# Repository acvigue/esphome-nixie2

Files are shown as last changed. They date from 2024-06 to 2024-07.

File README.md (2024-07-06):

# ESPHome for Nixie2

Includes custom component for HV5222 low-side shift register

Read more [here](https://vigue.me/nixie-clock)

Altium 3D Viewer & Assembly Preview: [here](https://365.altium.com/files/F7F2C198-6388-416A-9E94-9685C6B443AA)

Example configuration:

```yaml
esphome:
  name: nixieclock
  friendly_name: nixieclock
  on_boot:
    then:
      - number.set:
          id: nixie_1
          value: 9
      - number.set:
          id: nixie_2
          value: 9
      - number.set:
          id: nixie_3
          value: 9
      - number.set:
          id: nixie_4
          value: 9
      - number.set:
          id: nixie_5
          value: 9
      - number.set:
          id: nixie_6
          value: 9

esp32:
  board: esp32-s3-devkitc-1
  framework:
    type: esp-idf

# Enable logging
logger:
  level: WARN

external_components:
  - source: github://acvigue/esphome-nixie2
    components: [hv5222]
    refresh: 1s

# Enable Home Assistant API
api:
  encryption:
    key: "##########"

ota:
  - platform: esphome
    password: "##########"

wifi:
  ssid: !secret wifi_ssid
  password: !secret wifi_password

  # Enable fallback hotspot (captive portal) in case wifi connection fails
  ap:
    ssid: "Nixieclock Fallback Hotspot"
    password: "##########"

globals:
  - id: military_time
    type: bool
    restore_value: yes
    initial_value: "false"
  - id: cleaning
    type: bool
    restore_value: no
    initial_value: "false"

light:
  - platform: esp32_rmt_led_strip
    rgb_order: GRB
    pin: 21
    num_leds: 6
    rmt_channel: 1
    chipset: ws2812
    is_rgbw: True
    name: "Backlight"
    restore_mode: RESTORE_DEFAULT_OFF
  - platform: monochromatic
    output: calibrated_oe_out
    id: oe
    name: "HV5222 OE"
    restore_mode: RESTORE_DEFAULT_OFF

spi:
  id: spi_hv5222
  clk_pin: 12
  mosi_pin: 10
  interface: software

hv5222:
  - id: myHV5222
    spi_id: spi_hv5222
    data_rate: 10MHz
    spi_mode: MODE0
    count: 2

output:
  - platform: ledc
    pin: 11
    frequency: 18kHz
    id: oe_out
    inverted: True
  - platform: template
    id: calibrated_oe_out
    type: float
    write_action:
      - if:
          condition:
            lambda: return state > 0;
          then:
            - output.set_level:
                id: oe_out
                level: !lambda |-
                  const int min_percentage=40;
                  float min=static_cast<float>(min_percentage)/100.0f;
                  float k=(1.0f-min)/0.99f;
                  float m=(0.99f-1.0f+min)/0.99f;
                  return k*state+m;
          else:
            - output.set_level:
                id: oe_out
                level: 0

number:
  - platform: hv5222
    id: nixie_6
    count_back: True
    count_back_speed: 50
    hv5222: myHV5222
    pins: [0, 1, 2, 3, 4, 5, 6, 7, 8, 9]
  - platform: hv5222
    id: nixie_5
    count_back: True
    count_back_speed: 50
    hv5222: myHV5222
    pins: [10, 11, 12, 13, 14, 15, 16, 17, 18, 19]
  - platform: hv5222
    id: nixie_4
    count_back: True
    count_back_speed: 50
    hv5222: myHV5222
    pins: [20, 21, 22, 23, 24, 25, 26, 27, 28, 29]
  - platform: hv5222
    id: nixie_3
    count_back: True
    count_back_speed: 50
    hv5222: myHV5222
    pins: [30, 31, 32, 33, 34, 35, 36, 37, 38, 39]
  - platform: hv5222
    id: nixie_2
    count_back: True
    count_back_speed: 50
    hv5222: myHV5222
    pins: [40, 41, 42, 43, 44, 45, 46, 47, 48, 49]
  - platform: hv5222
    id: nixie_1
    count_back: True
    count_back_speed: 50
    hv5222: myHV5222
    pins: [50, 51, 52, 53, 54, 55, 56, 57, 58, 59]

time:
  - platform: sntp
    id: sntp_time
    on_time:
      - cron: "0 0 * * * *"
        then:
          - globals.set:
              id: cleaning
              value: "true"
          - repeat:
              count: 45
              then:
                - number.increment:
                    id: nixie_1
                - number.increment:
                    id: nixie_2
                - number.increment:
                    id: nixie_3
                - number.increment:
                    id: nixie_4
                - number.increment:
                    id: nixie_5
                - number.increment:
                    id: nixie_6
                - delay: 0.25s
          - globals.set:
              id: cleaning
              value: "false"
      - cron: "* * * * * *"
        then:
          lambda: |
            if(!id(cleaning)) {
            auto time = id(sntp_time).now();
            auto call1 = id(nixie_1).make_call();
            call1.set_value(time.second % 10);
            call1.perform();
            auto call2 = id(nixie_2).make_call();
            call2.set_value(time.second / 10);
            call2.perform();
            auto call3 = id(nixie_3).make_call();
            call3.set_value(time.minute % 10);
            call3.perform();
            auto call4 = id(nixie_4).make_call();
            call4.set_value(time.minute / 10);
            call4.perform();
            auto hours = time.hour;
            if(!id(military_time)) {
            hours = hours % 12;
            if (hours == 0) hours = 12;
            }
            auto call5 = id(nixie_5).make_call();
            call5.set_value(hours % 10);
            call5.perform();
            auto call6 = id(nixie_6).make_call();
            call6.set_value(hours / 10);
            call6.perform();
            }

captive_portal:
```

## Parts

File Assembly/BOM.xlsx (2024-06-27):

Line # | Name | Description | Designator | Revision ID | Revision State | Revision Status | Quantity | Manufacturer 1 | Manufacturer Part Number 1 | Manufacturer Lifecycle 1 | Supplier 1 | Supplier Part Number 1 | Supplier Unit Price 1 | Supplier Subtotal 1
 | HV5222PG-G | EL Driver, 32-Segment, PQFP44 | *1, *2 | CMP-00024-00006-1 | Draft | Up to date | 2 | Microchip Supertex | HV5222PG-G | Unknown | Heisener | HV5222PG-G | 6.74 | 13.48
 | PTH-M3D5X5 | Plated Thru-Hole M3 D5X5 | *3, *4, *5, *6 | CMP-010-00024-1 | Draft | Out of date | 4
 | C3216X5R1C476M160AB | Multilayer Ceramic Capacitors 47uF ±20% 16V X5R SMD 1206 | C1, C3, C5, C6, C13, C14, C15, C16 | CMP-2000-07442-2 | Released | Up to date | 8 | TDK | C3216X5R1C476M160AB | Volume Production | Mouser | 810-C3216X5R1C476M | 0.459 | 4.59
 | GCJ43DR72E224KXJ1L | 0.22uF ±10% 250V Ceramic Capacitor X7R 1812 (4532 Metric) | C2, C4 | CMP-06035-007963-1 | New From Design | Up to date | 2 | Murata | GCJ43DR72E224KXJ1L | Volume Production | Mouser | 81-GCJ43DR72E224KX1L | 1.02 | 2.04
 | GRM21BR61C106KE15L | Chip Multilayer Ceramic Capacitors for General Purpose, 0805, 10uF, X5R, 15%, 10%, 16V | C7 | CMP-2007-03453-2 | New From Design | Up to date | 1 | Murata | GRM21BR61C106KE15L | Volume Production | Mouser | 81-GRM21BR61C106KE15 | 0.16 | 0.16
 | 08052U101JAT2A |  | C8 | CMP-2007-04861-1 | Released | Up to date | 1 | Kyocera AVX | 08052U101JAT2A | Volume Production | Mouser | 581-08052U101JAT2A | 0.3 | 0.3
 | C0805C103K2RACTU | CAP CER 10000PF 200V X7R 0805 | C9 | CMP-2007-00259-2 | New From Design | Up to date | 1 | KEMET | C0805C103K2RACTU | Volume Production
 | C0805C223K5RACTU | CAP CER 0.022UF 50V X7R 0805 | C10 | CMP-2007-00338-2 | New From Design | Up to date | 1 | KEMET | C0805C223K5RACTU | Volume Production
 | 08051C104KAT2A | General Purpose Ceramic Capacitor, 0805, 100nF, 10%, X7R, 15%, 100V | C11, C12 | CMP-2007-04174-2 | Released | Up to date | 2 | Kyocera AVX | 08051C104KAT2A | Volume Production | Mouser | 581-08051C104KAT2A | 0.28 | 0.56
 | UMK107AB7105KA-T | Ceramic Capacitor General Use 1uF ±10% 50V X7R 0603 | C17 | CMP-2000-07531-4 | Released | Up to date | 1 | Taiyo Yuden | UMK107AB7105KA-T | Not Recommended for New Design | Mouser | 963-UMK107AB7105KA-T | 0.26 | 0.26
 | GRM188R60J476ME15D | Chip Multilayer Ceramic Capacitors for General Purpose, 0603, 47uF, X5R, 15%, 20%, 6.3V | C18, C19, C20, C21, C22, C23, C24 | CMP-2000-05444-2 | New From Design | Up to date | 7 | Murata | GRM188R60J476ME15D | Volume Production | Mouser | 81-GRM188R60J476ME5D | 0.241 | 2.41
 | RFN1LAM6STR | DIODE GEN PURP 600V 800MA PMDTM | D1 | CMP-08972-000003-1 | New From Design | Up to date | 1 | Rohm | RFN1LAM6STR | Volume Production | Mouser | 755-RFN1LAM6STR | 0.42 | 0.42
 | USB4110-GF-A | CONN USB 2.0 TYPE-C R/A SMT | J1 | CMP-245163-000002-1 | New From Design | Up to date | 1 | Global Connector Technology | USB4110-GF-A | Volume Production | Mouser | 640-USB4110-GF-A | 1.35 | 1.35
 | TC2030-IDC-NL | CABLE ADAPTER 6 POS | J2 | CMP-070-000001-2 | Draft | Up to date | 1
 | IN-14 |  | N1, N2, N3, N4, N5, N6 | CMP-087-000009-1 | Draft | Up to date | 6
 | IRLR3110ZTRPBF | MOSFET N-CH 100V 42A DPAK | Q1 | CMP-32901-000150-1 | New From Design | Up to date | 1 | Infineon | IRLR3110ZTRPBF | Volume Production | Mouser | 942-IRLR3110ZTRPBF | 1.69 | 1.69
 | CSD15571Q2 | MOSFET N-CH 20V 22A 6SON | Q2, Q3 | CMP-04962-000051-1 | New From Design | Up to date | 2 | Texas Instruments | CSD15571Q2 | Volume Production | Mouser | 595-CSD15571Q2 | 0.41 | 0.82
 | MMBT3904LT1G | General Purpose Transistor, NPN Silicon, 3-Pin SOT-23, Pb-Free, Tape and Reel | Q4, Q5, Q6 | CMP-1048-00631-1 | Released | Up to date | 3 | ON Semiconductor | MMBT3904LT1G | Volume Production | Digikey | MMBT3904LT1GOSCT-ND | 0.16 | 0.48
 | ERJ-8ENF1004V |  | R1 | CMP-2003-00020-1 | Released | Up to date | 1 | Panasonic | ERJ-8ENF1004V | Not Recommended for New Design | Mouser | 667-ERJ-8ENF1004V | 0.17 | 0.17
 | RC0805FR-0763K4L |  | R2 | CMP-2001-01229-1 | Released | Up to date | 1 | Yageo | RC0805FR-0763K4L | Volume Production | Mouser | 603-RC0805FR-0763K4L | 0.1 | 0.1
 | ERJ-6GEYJ220V |  | R3 | CMP-2001-00374-1 | Released | Up to date | 1 | Panasonic | ERJ-6GEYJ220V | Volume Production | Mouser | 667-ERJ-6GEYJ220V | 0.1 | 0.1
 | ERA3AEB1403V |  | R4, R8 | CMP-2000-00911-1 | Released | Up to date | 2 | Panasonic | ERA-3AEB1403V | Unknown | Mouser | 667-ERA-3AEB1403V | 0.13 | 0.26
 | RC0805FR-0710KL | Chip Resistor, 10 KOhm, +/- 1%, 0.125 W, -55 to 155 degC, 0805 (2012 Metric), RoHS, Tape and Reel | R5, R7, R19, R21, R22, R23, R24, R25, R26, R27, R28 | CMP-1659-00013-4 | Released | Up to date | 11 | Yageo | RC0805FR-0710KL | Volume Production | Mouser | 603-RC0805FR-0710KL | 0.017 | 0.187
 | ERJ8BWFR020V |  | R6 | CMP-2003-00770-1 | Released | Up to date | 1 | Panasonic | ERJ-8BWFR020V | Volume Production | Mouser | 667-ERJ-8BWFR020V | 0.72 | 0.72
 | CRCW06035K10FKEA | RES Thick Film, 5.1kΩ, 1%, 0.1W, 100ppm/°C, 0603 | R9, R10 | CMP-1012-00590-3 | New From Design | Up to date | 2 | Bourns | CR0603-FX-5101ELF | Volume Production | Mouser | 652-CR0603FX-5101ELF | 0.009 | 0.09
 | CRCW120610M0FKEA | RES Thick Film, 10MΩ, 1%, 0.25W, 100ppm/°C, 1206 | R11 | CMP-1014-00962-3 | New From Design | Up to date | 1 | Yageo | RC1206FR-0710ML | Volume Production | Digikey | 311-10.0MFRCT-ND | 0.1 | 0.1
 | ERJ-6ENF1000V | RES SMD 100 OHM 1% 1/8W 0805 | R12 | CMP-2001-04374-6 | Released | Up to date | 1 | Panasonic | ERJ-6ENF1000V | Volume Production | Mouser | 667-ERJ-6ENF1000V | 0.1 | 0.1
 | ERJ-6ENF6492V |  | R13 | CMP-2001-00264-1 | Released | Up to date | 1 | Panasonic | ERJ-6ENF6492V | Volume Production | Digikey | P64.9KCCT-ND | 0.1 | 0.1
 | ERJ-3EKF4022V | RES SMD 40.2K OHM 1% 1/10W 0603 | R14 | CMP-2000-00486-2 | Released | Up to date | 1 | Panasonic | ERJ-3EKF4022V | Volume Production | Digikey | P40.2KHCT-ND | 0.1 | 0.1
 | ERJ3EKF1002V | Chip Resistor, 10 KOhm, +/- 1%, 0.1 W, -55 to 155 degC, 0603 (1608 Metric), RoHS, Tape and Reel | R15, R32 | CMP-1012-00623-3 | Released | Up to date | 2 | Bourns | CR0603-FX-1002ELF | Volume Production | Mouser | 652-CR0603FX-1002ELF | 0.009 | 0.09
 | RC0805FR-0751K1L |  | R16, R17, R18, R20 | CMP-2001-01183-1 | Released | Up to date | 4 | Yageo | RC0805FR-0751K1L | Volume Production | Mouser | 603-RC0805FR-0751K1L | 0.016 | 0.16
 | RC0805FR-071KL | Chip Resistor, 1 KOhm, +/- 1%, 125 mW, -55 to 155 degC, 0805 (2012 Metric), RoHS, Tape and Reel | R29, R30, R31 | CMP-2100-03671-1 | Released | Up to date | 3 | Yageo | RC0805FR-071KL | Volume Production | Mouser | 603-RC0805FR-071KL | 0.016 | 0.16
 | 147873-1 | SWITCH TACTILE SPST-NO 0.05A 24V | SW1 | CMP-03407-000005-1 | New From Design | Up to date | 1 | TE Connectivity | 147873-1 | Unknown | Digikey | 450-2146-1-ND | 0.29 | 0.29
 | DA2032-ALD | No Description Available | U1 | CMP-080-000000-1 | Draft | Up to date | 1
 | LT3757EDD#PBF | IC REG CTRLR MULT TOPOLOGY 10DFN | U2 | CMP-09139-000444-1 | New From Design | Up to date | 1 | Analog Devices / Linear Technology | LT3757EDD#PBF | Volume Production | Mouser | 584-LT3757EDD#PBF | 6.66 | 6.66
 | AP33771DKZ-13 |  | U3 |  | Not managed |  | 1
 | TPSM33625FRDNR | No Description Available | U4 | CMP-054-000002-4 | Draft | Up to date | 1
 | LM1117MPX-3.3/NOPB | 800mA Low-Dropout Linear Regulator, 4-pin SOT-223, Pb-Free | U5 | CMP-0062-01639-4 | Released | Up to date | 1 | TI National Semiconductor | LM1117MPX33NOPB | Unknown
 | WS2812B-B | Intelligent control LED integrated light source | U6, U7, U8, U9, U10, U11 |  | Not managed |  | 6
 | ESP32-S3-WROOM-1-N8R8 | <a href="https://pricing.snapeda.com/parts/ESP32S3WROOM1N8R8/Espressif%20Systems/view-part?ref=eda">Check availability</a> | U12 |  | Not managed |  | 1

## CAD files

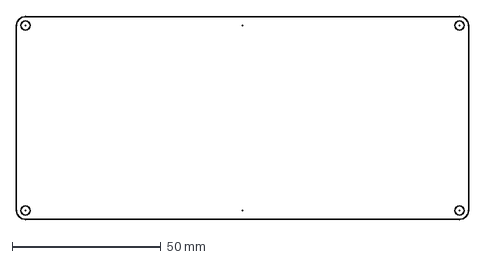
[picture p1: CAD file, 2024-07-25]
VixenBottom.dxf
152.3 x 68.5 mm

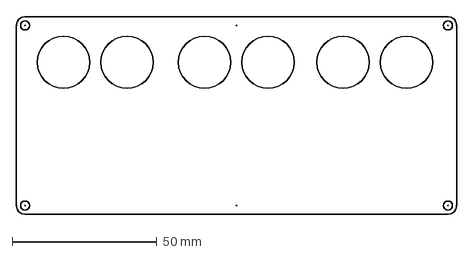
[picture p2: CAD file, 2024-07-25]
VixenTop.dxf
152.3 x 68.5 mm

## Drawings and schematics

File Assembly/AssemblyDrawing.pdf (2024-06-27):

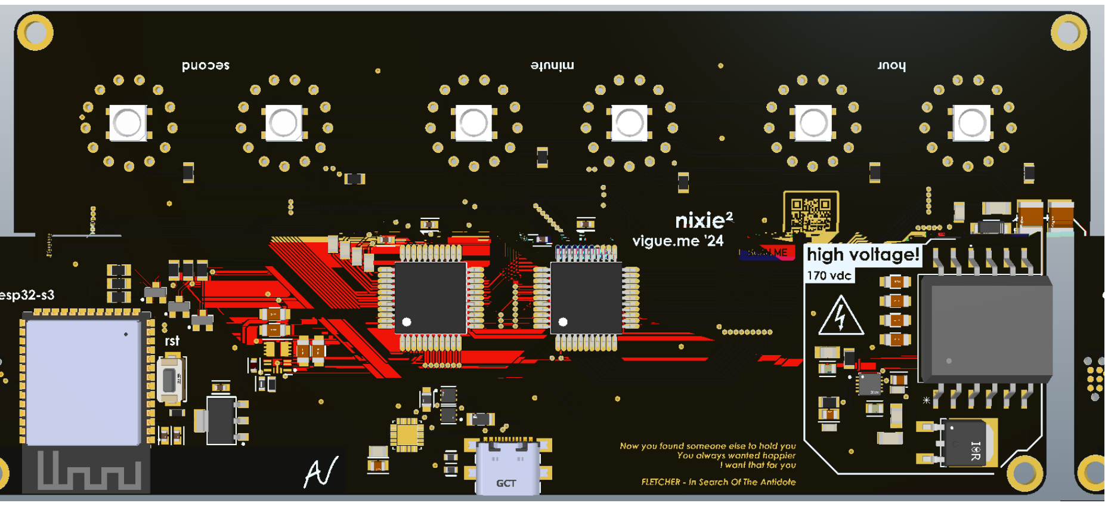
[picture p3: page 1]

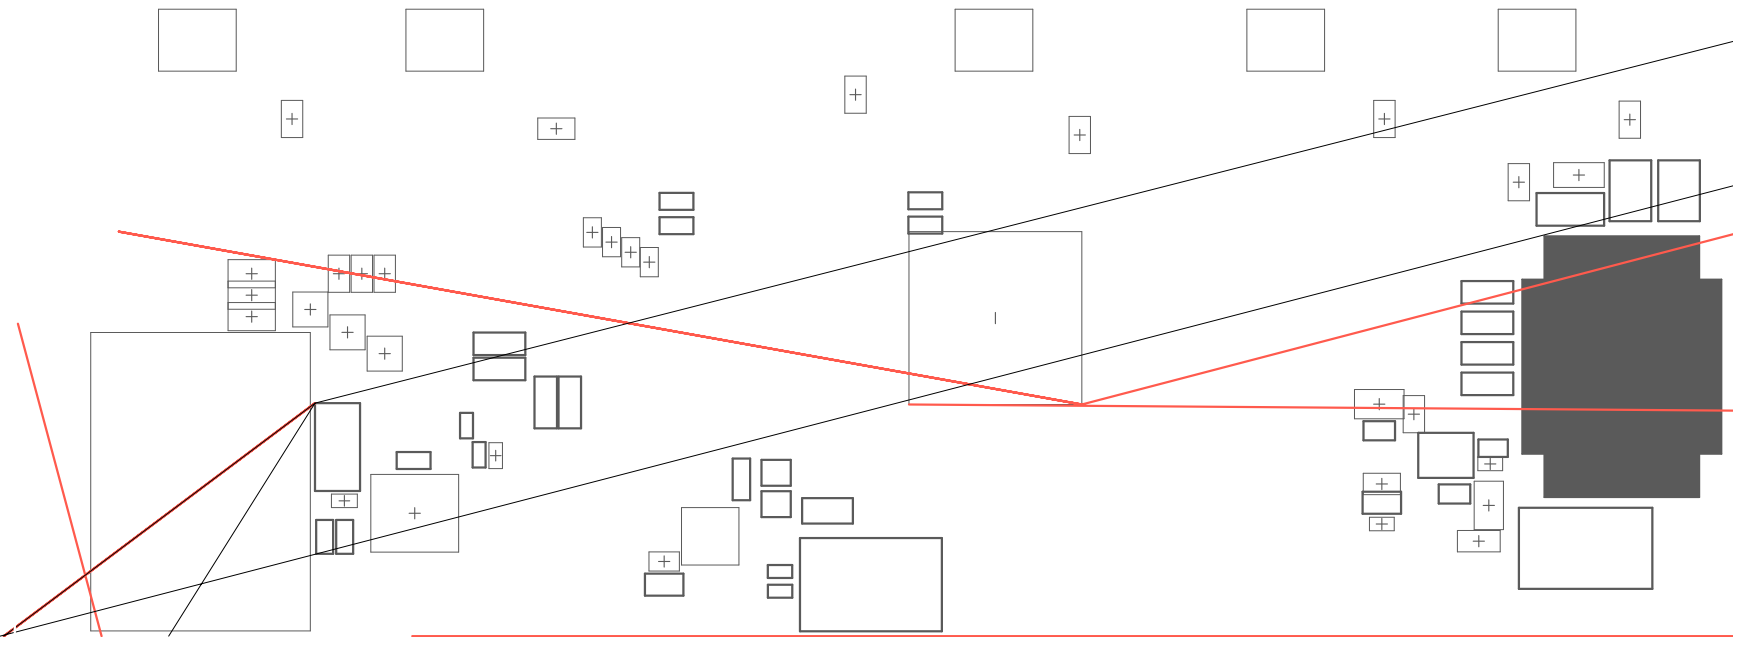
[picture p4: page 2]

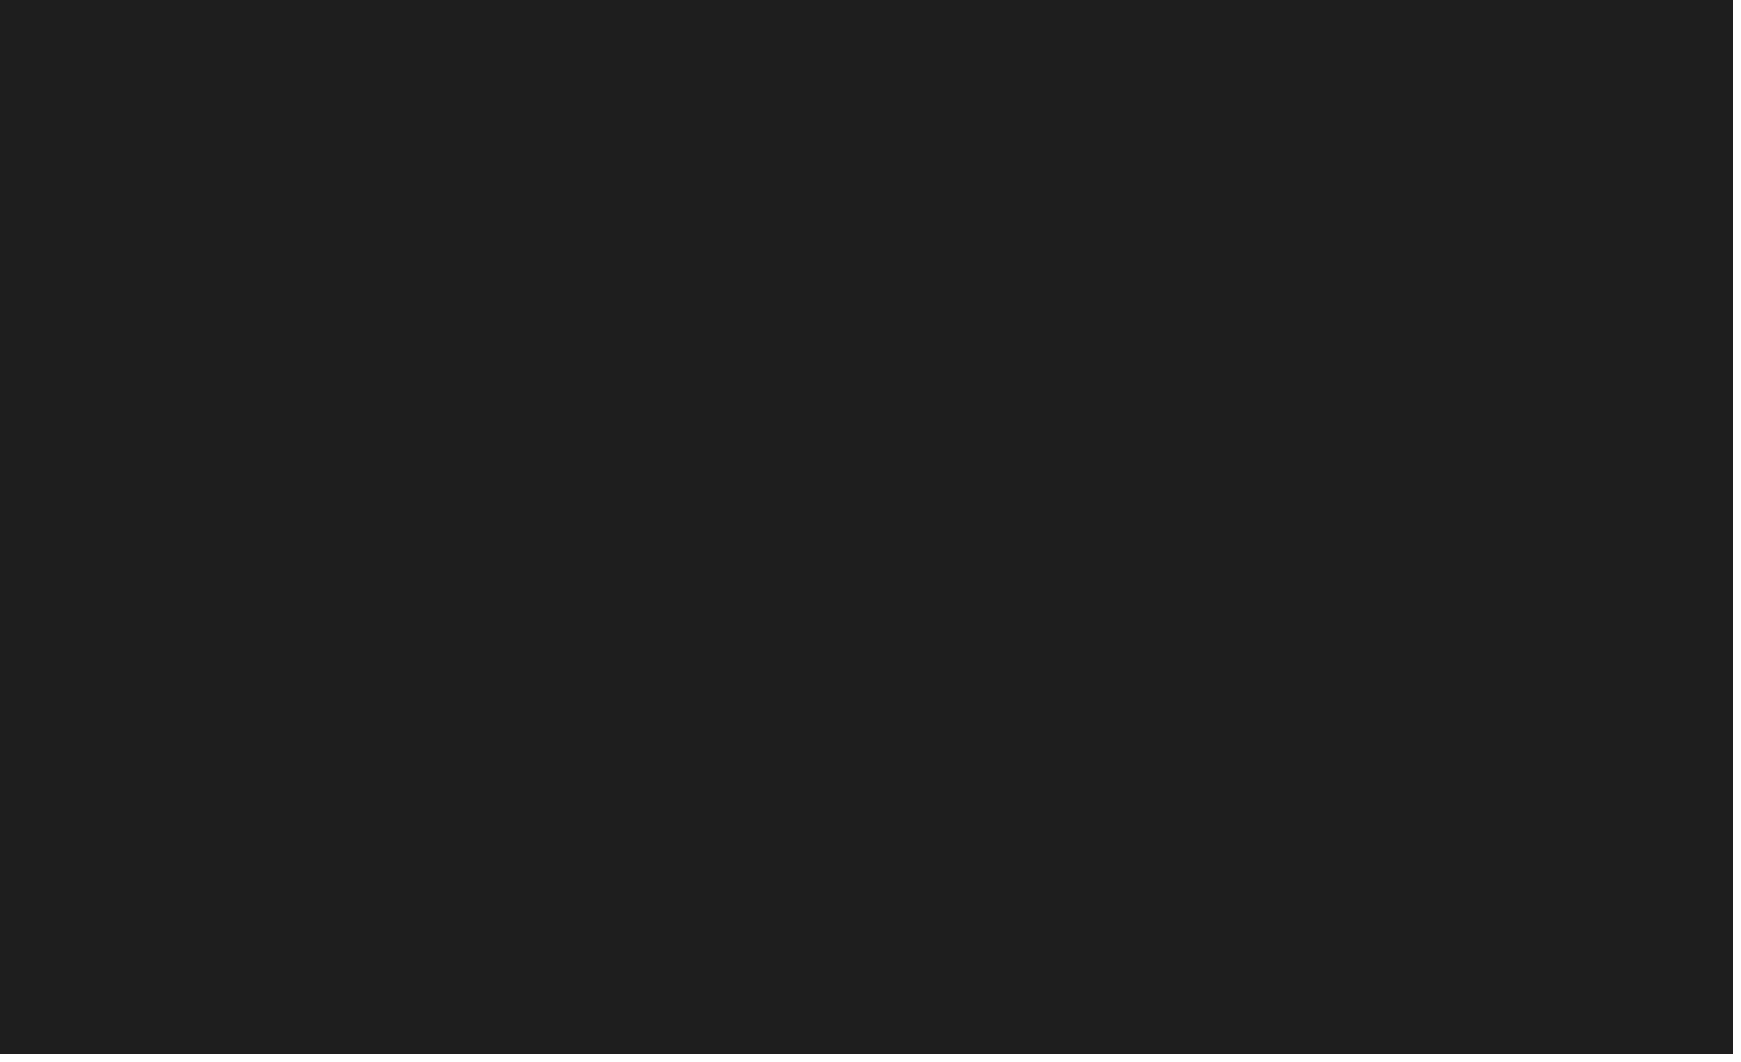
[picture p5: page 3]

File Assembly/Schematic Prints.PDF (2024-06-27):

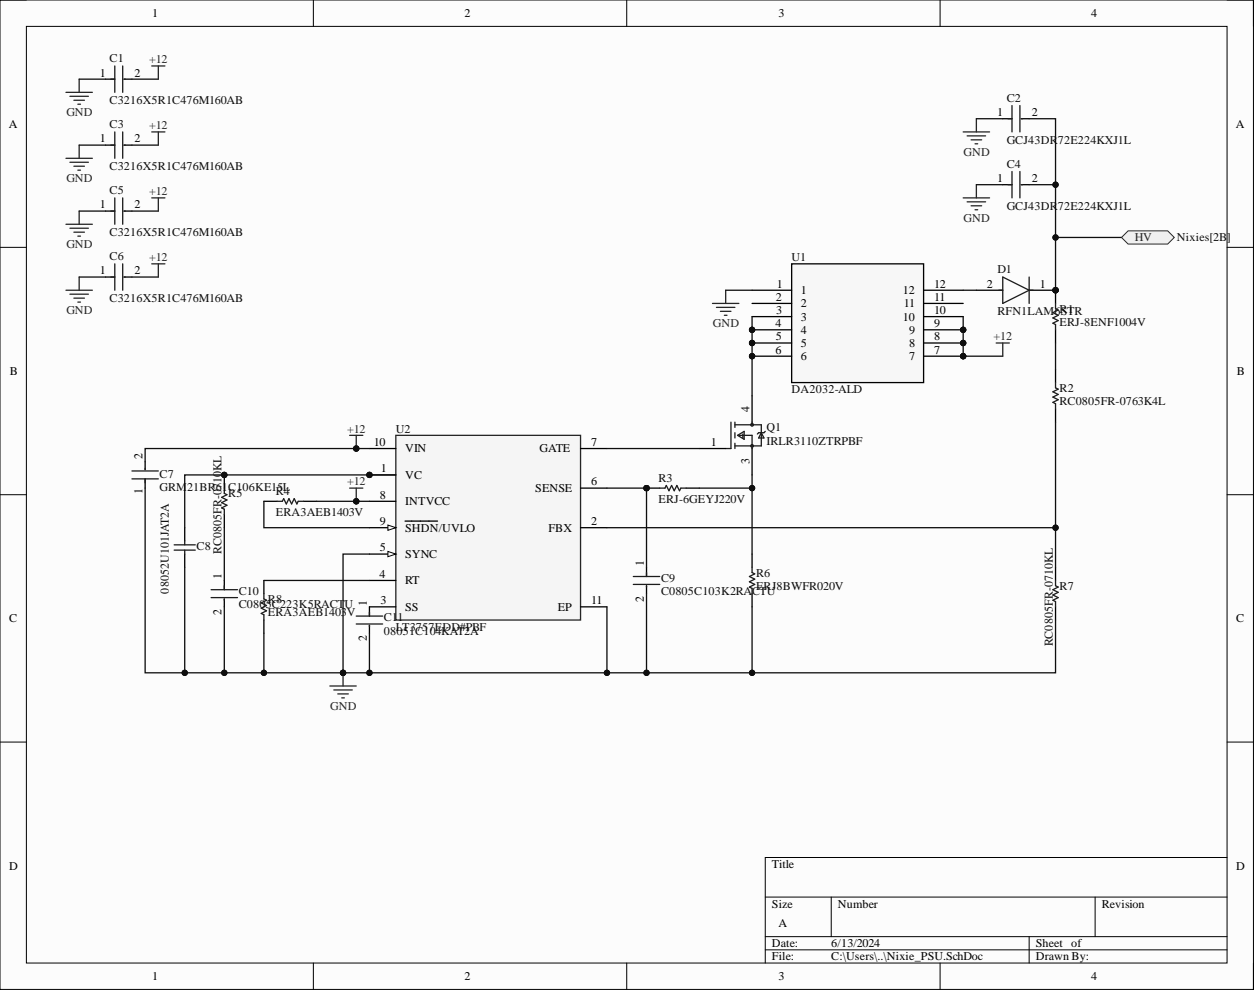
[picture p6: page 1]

U R8 ERA3AEB1403V | 3

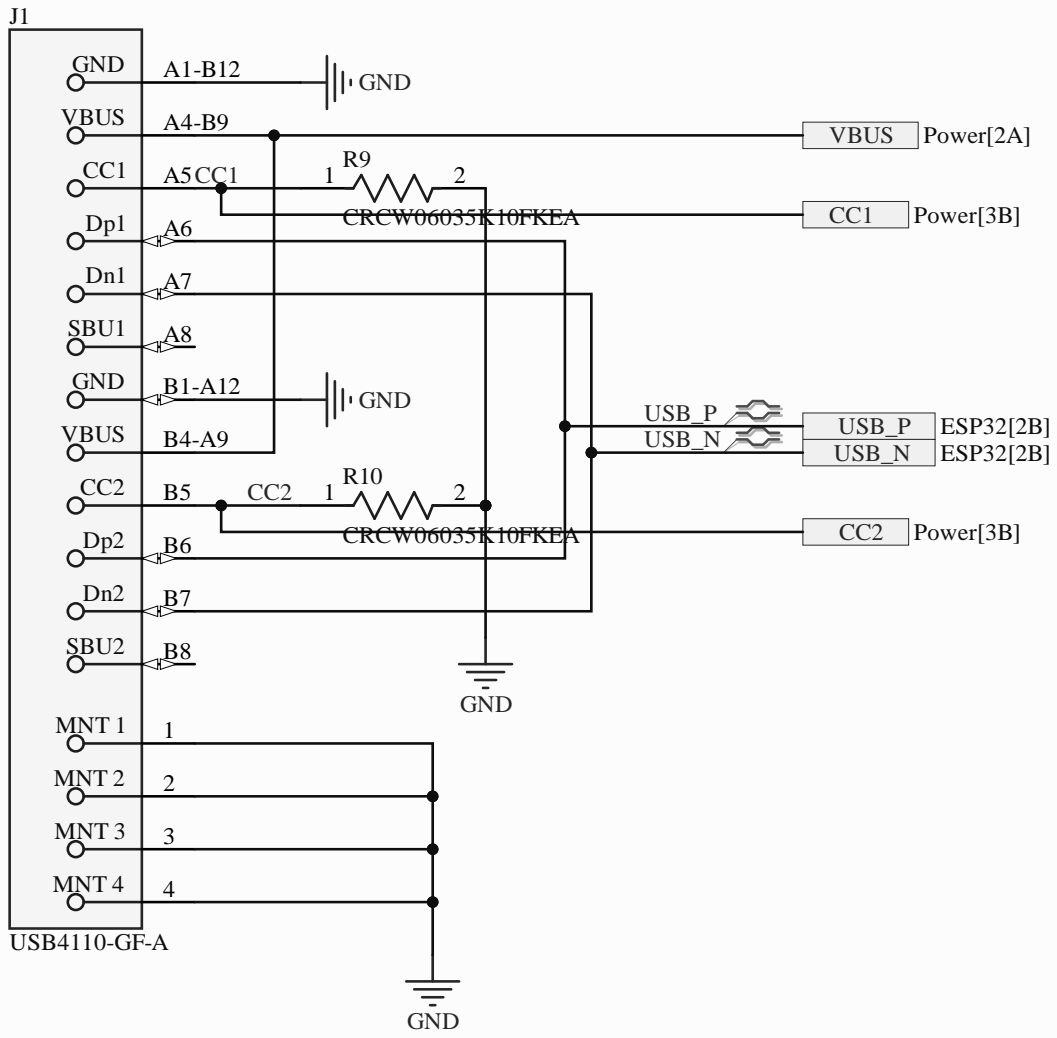
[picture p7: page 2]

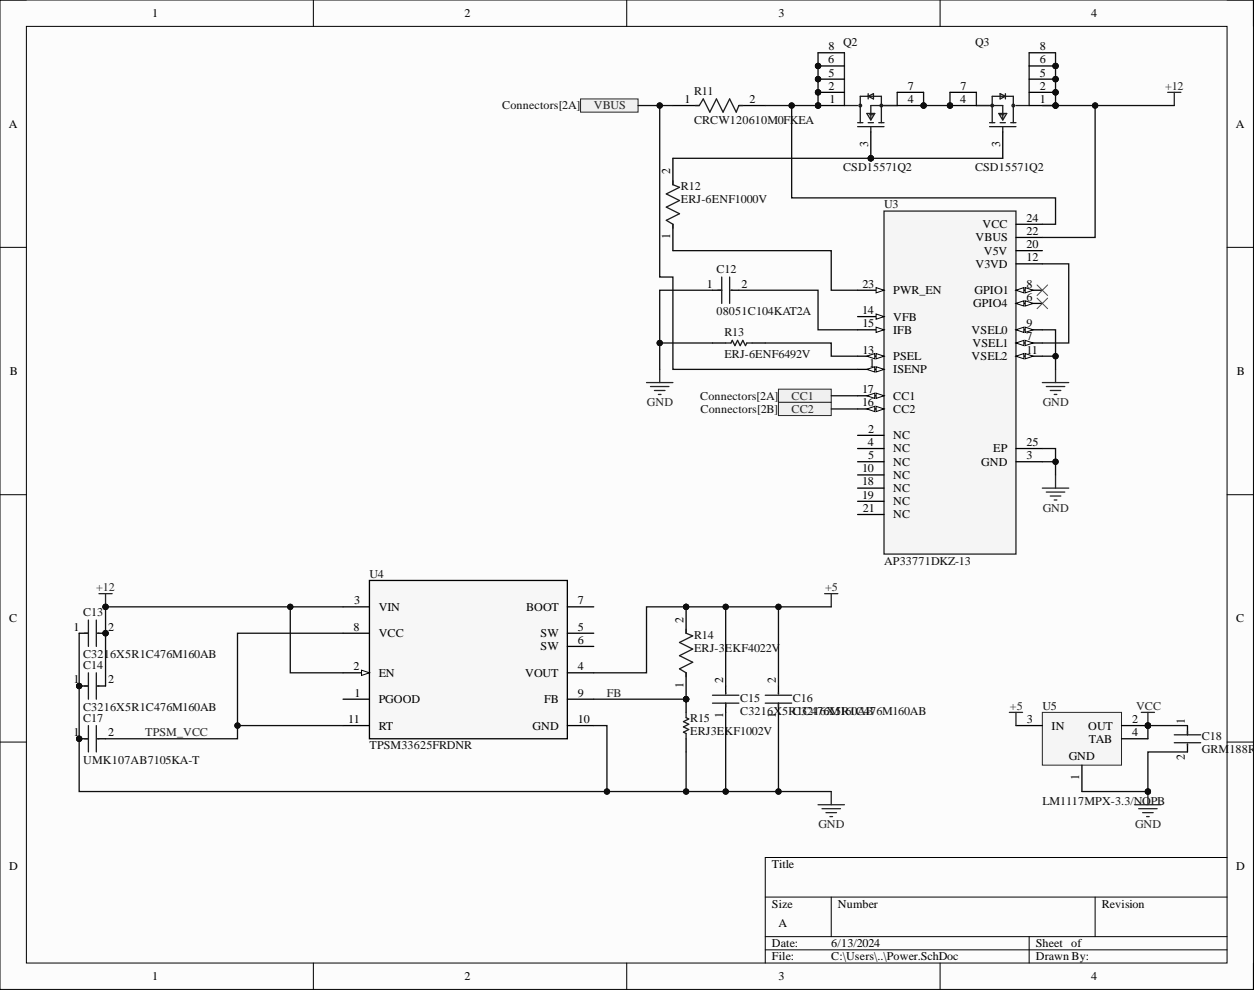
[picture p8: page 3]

CRCW120610M0FKEA

CSD15571Q2 | U3

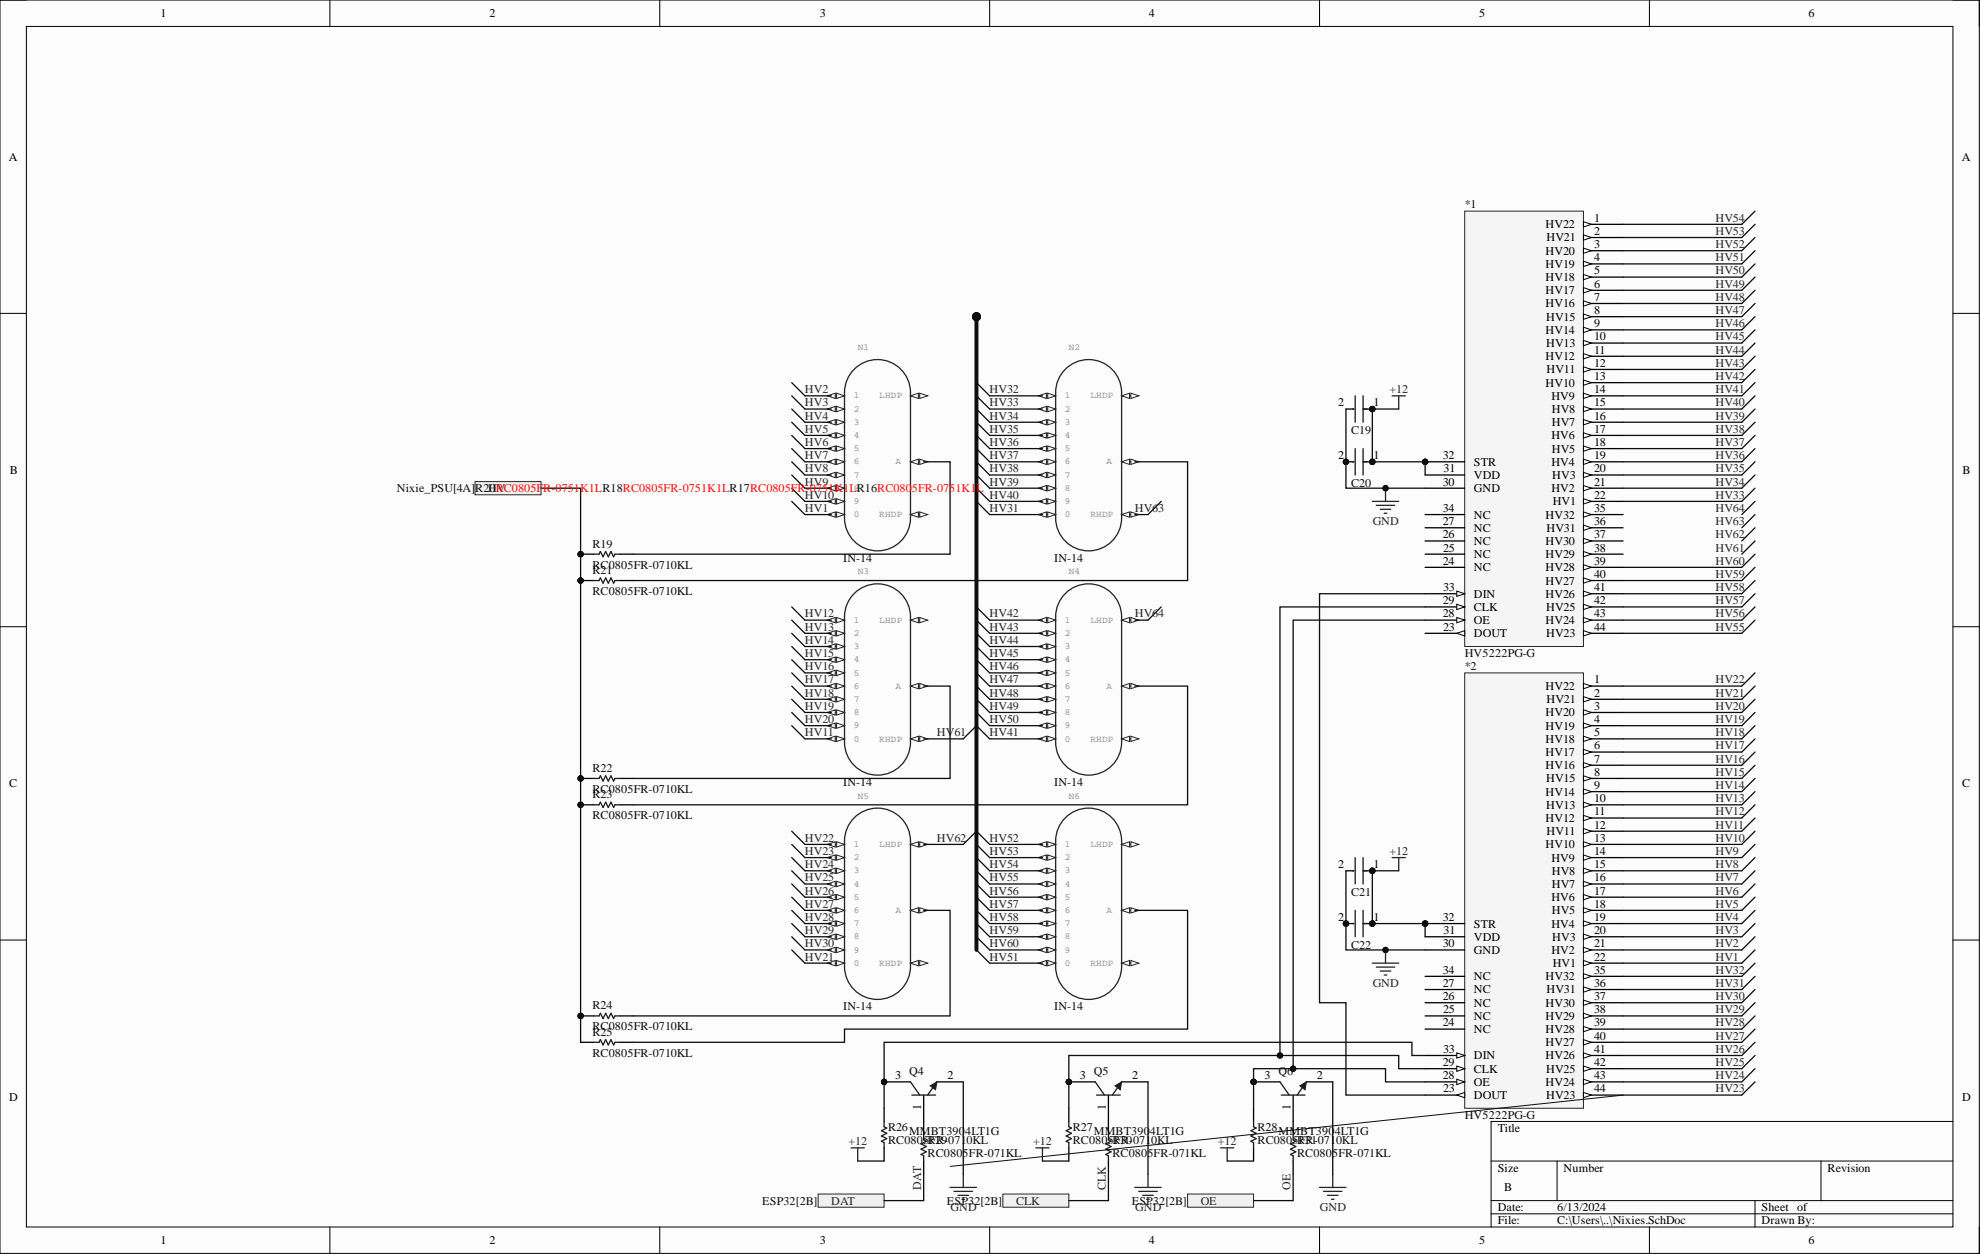
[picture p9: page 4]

OE 28 CLK 29

+12 | +12 | DOUT 23

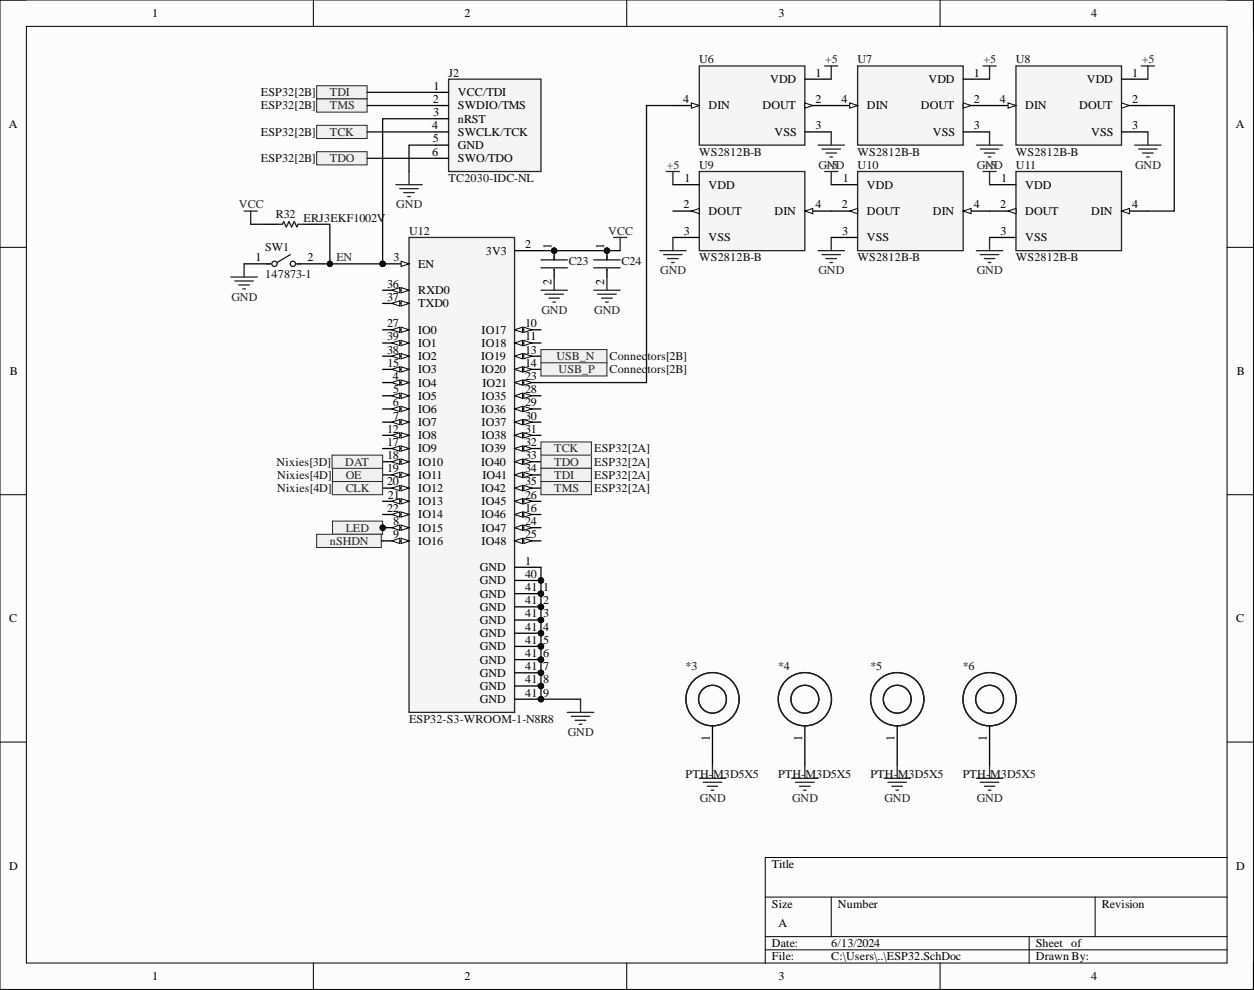
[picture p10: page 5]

SWCLK/TCK 4

SWO/TDO 6 | WS2812B-B WS2812B-B WS2812B-B U9 U10 U11

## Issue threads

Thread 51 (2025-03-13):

Resistor value

ripnet, 2025-03-13:
On your site, you mentioned that you had to replace a resistor. Was this R11? I don't see this updated anywhere.

Closed 2025-03-16.

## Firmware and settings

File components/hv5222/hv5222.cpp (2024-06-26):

#include "hv5222.h"
#include "esphome/core/log.h"
// #include <sstream>
// #include <string>
// #include <iomanip>

namespace esphome {
  namespace hv5222 {

    static const char* const TAG = "HV5222";

    void HV5222component::setup() {
      ESP_LOGD(TAG, "Setting up HV5222 via SPI bus...");
      this->spi_setup();

      //fill output_bytes_ with 1
      for (auto& byte : this->output_bytes_)
        byte = 0xFF;

      //set last byte to 0x00;
      this->output_bytes_[(this->chip_count_ * 4) - 1] = 0xFE; //0b11111110

      this->write_bytes();
    }

    void HV5222component::dump_config() { ESP_LOGCONFIG(TAG, "HV5222:"); }

    void HV5222component::digital_write_(uint16_t pin, bool value) {
      if (pin > this->max_pins_ * 8) {
        ESP_LOGE(TAG, "Pin %u is out of range! Maximum pin number with %u chips is %u.", pin, this->chip_count_,
          (this->max_pins_ * 8));
        return;
      }
      if (!value) {
        this->output_bytes_[(this->max_pins_) - (pin / 8) - 1] |= (1 << (pin % 8));
      }
      else {
        this->output_bytes_[(this->max_pins_) - (pin / 8) - 1] &= ~(1 << (pin % 8));
      }
      this->write_bytes();
    }

    void HV5222component::write_bytes() {
#ifdef ESP_LOGV
      ESP_LOGV(TAG, "Writing out %u bytes via SPI bus in this order:", this->output_bytes_.size());
      for (auto byte = this->output_bytes_.rbegin(); byte != this->output_bytes_.rend(); ++byte)
        ESP_LOGV(TAG, "  0x%02X", *byte);
#endif
      this->write_array(this->output_bytes_);
    }

    void HV5222Pin::digital_write(bool value) { this->parent_->digital_write_(this->pin_, value != this->inverted_); }

    std::string HV5222Pin::dump_summary() const { return str_snprintf("%u GPIO output via HV5222", 27, this->pin_); }

  }  // namespace hv5222
}  // namespace esphome

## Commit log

2024-06-26 oe pin
2024-06-27 add Altium design files
    [AP33771DKZ-13.PcbLib, AP33771DKZ-13.SchLib, BOM.xlsx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]
